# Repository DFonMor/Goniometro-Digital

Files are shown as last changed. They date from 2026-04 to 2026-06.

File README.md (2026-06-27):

# Goniometro-Digital
Repositório para o desenvolvimento de um dispositivo para a disciplina de Projeto Integrador em Engenharia Mecatrônica

# Introdução

O presente projeto tem como objetivo o desenvolvimento de um goniômetro digital, destinado à medição da amplitude de movimento de articulações, com foco em aplicações na área de fisioterapia. Diferentemente dos modelos analógicos tradicionais, que dependem de leitura manual e anotação dos resultados, a solução proposta busca automatizar tanto a aquisição quanto o armazenamento dos dados.

O sistema será composto por um sensor de posição acoplado a um microcontrolador (ESP32), responsável por realizar a leitura e o processamento dos dados, além de comunicar as medições a um aplicativo mobile por meio de conexão sem fio. O aplicativo permitirá a visualização em tempo real, bem como o armazenamento do histórico de medições associadas a cada paciente.

Essa abordagem visa aumentar a precisão das medições, reduzir erros humanos e proporcionar maior praticidade ao profissional durante o acompanhamento da evolução dos pacientes, centralizando todas as informações em uma única plataforma digital.

# Sistema

O sistema proposto é composto por três módulos principais: o dispositivo embarcado, o aplicativo mobile e o mecanismo de armazenamento de dados.

O dispositivo embarcado é baseado no microcontrolador ESP32, responsável pela aquisição dos sinais provenientes do sensor por meio de seu conversor analógico-digital (ADC). A partir dessas leituras, o sistema realiza o processamento necessário para obtenção da medida de ângulo das articulações.

A comunicação entre o dispositivo e o usuário é realizada por meio de Bluetooth Low Energy (BLE), permitindo a transmissão dos dados em tempo real para um dispositivo móvel. A escolha do BLE foi motivada pelo seu baixo consumo energético, simplicidade de conexão com smartphones e adequação a aplicações portáteis, características essenciais para o contexto de uso do goniômetro.

O aplicativo mobile será desenvolvido utilizando o framework React Native, sendo responsável por estabelecer a conexão com o ESP32, receber os dados transmitidos e apresentá-los ao usuário em tempo real. Além disso, o aplicativo permitirá o armazenamento das medições, possibilitando o acompanhamento do histórico de cada paciente, conforme previsto no escopo do projeto.

## Back-End

O back-end do projeto é composto pelo firmware desenvolvido para o microcontrolador ESP32, responsável pela leitura do sensor analógico e transmissão dos dados via Bluetooth Low Energy (BLE). O firmware foi implementado em C++ utilizando o framework Arduino, com as seguintes características:

- **Leitura analógica**: O ESP32 realiza a leitura do sinal proveniente de um potenciômetro linear (ou sensor de ângulo) conectado a um pino ADC, com resolução de 12 bits (0–4095) e atenuação configurada para a faixa de 0 a 3,3 V.

- **Conversão para tensão**: O valor cru do ADC é convertido para tensão (em volts) utilizando a referência de 3,3 V, resultando em valores entre 0 e 3,3 V.

- **Comunicação BLE**: O ESP32 atua como periférico BLE, anunciando o serviço com UUID personalizado e disponibilizando uma característica para leitura/escrita/notificação. O dispositivo aguarda comandos enviados pelo aplicativo mobile e responde com pacotes de dados estruturados.

- **Protocolo de comunicação**: Os dados são transmitidos em pacotes com o formato `[FLAG_1][FLAG_2][LEN][DATA ...][CHECKSUM]`, onde:
  - `FLAG_1` e `FLAG_2` identificam o tipo de mensagem (requisição, resposta ou calibração);
  - `LEN` indica o número de bytes em `DATA` + `CHECKSUM`;
  - `CHECKSUM` é calculado como a soma simples dos bytes anteriores.
  - Os comandos suportados incluem `START` (início da transmissão), `STOP` (interrupção da transmissão) e `CALIBRATE` (solicitação de calibração do zero).

- **Resposta do dispositivo**: O ESP32 envia pacotes de resposta contendo a tensão medida em centésimos de volt (HIGH e LOW), juntamente com o checksum correspondente.

- **Persistência de calibração**: O firmware armazena o offset de calibração (valor do ADC correspondente ao ângulo zero) na memória flash (via `Preferences`), garantindo que a calibração seja mantida mesmo após reinicializações.

O firmware foi projetado para ser estável, com baixo consumo de energia e compatível com as especificações do hardware do goniômetro.

---

## Front-End

O desenvolvimento do front-end é realizado por meio de um aplicativo mobile utilizando o framework React Native com Expo. O aplicativo é responsável por estabelecer a interface entre o usuário e o dispositivo embarcado, permitindo a visualização, interação e armazenamento das medições realizadas.

A arquitetura do aplicativo foi organizada em camadas (serviços, componentes, utilitários e contextos) para facilitar a manutenção e a evolução do código. A comunicação com o ESP32 é feita via Bluetooth Low Energy (BLE) utilizando a biblioteca `react-native-ble-plx`, com suporte a modo de simulação (mock) para testes sem hardware.

### Funcionalidades implementadas

- **Conexão com o dispositivo**  
  Busca e conexão com o ESP32 via BLE, com indicação visual do status (conectado, conectando, desconectado). O aplicativo permite iniciar/parar a transmissão de dados (comandos START/STOP) e desconectar completamente, mantendo a lógica de controle separada para maior flexibilidade.

- **Recepção e processamento de dados em tempo real**  
  Leitura contínua dos pacotes BLE enviados pelo microcontrolador, com validação de integridade (verificação de checksum) e parsing dos campos. Os dados de tensão são convertidos em ângulo utilizando uma função de mapeamento linear calibrada. Um filtro de mediana com janela de 12 amostras é aplicado para suavizar as leituras e reduzir ruídos.

- **Exibição das medições**  
  Apresentação clara e direta dos valores de tensão (V) e ângulo (°) na tela principal, com atualização dinâmica a cada novo pacote recebido. O ângulo é exibido em destaque, facilitando a leitura durante o uso clínico.

- **Perfil do Paciente Expandido**  
  Gerenciamento completo de pacientes, com criação, edição e exclusão de perfis. Cada perfil armazena:
  - Nome (obrigatório)
  - Data de nascimento
  - Sexo (Masculino, Feminino, Outro)
  - Lado afetado (Direito, Esquerdo, Ambos)
  - Diagnóstico / condição clínica
  - Número de prontuário
  - Telefone para contato
  A edição é feita por meio de um modal com formulário organizado, incluindo campos com máscara (data) e seletores (sexo, lado afetado).

- **Seleção de Movimento**  
  Antes de salvar uma medição, o usuário pode selecionar o tipo de movimento realizado (Punho, Cotovelo, Joelho, Tornozelo, Outro). O movimento é registrado junto com a medição e exibido no histórico, permitindo filtrar ou categorizar os dados futuramente.

- **Registro de medições**  
  Funcionalidade para salvar a medição atual no perfil do paciente ativo, associando-a a um timestamp e ao movimento selecionado. Os dados são armazenados localmente no dispositivo utilizando AsyncStorage, com estrutura organizada por paciente.

- **Histórico completo com anotações e exclusão**  
  Tela dedicada (modal) que exibe todas as medições de um paciente, com as seguintes ações por item:
  - **Visualização de anotação**: cada medição pode ter uma anotação de texto livre, exibida na lista com suporte a expansão/colapso (ver mais/ver menos).
  - **Edição de anotação**: ao tocar no ícone ⋮, o usuário pode adicionar ou editar a anotação através de um modal com campo de texto.
  - **Exclusão de medição**: opção para deletar uma medição com confirmação, removendo-a do armazenamento e da lista.

- **Calibração do zero**  
  O aplicativo permite calibrar o ponto de zero (0°) do sensor, armazenando a tensão correspondente a essa posição no perfil do paciente. A calibração é aplicada em todas as medições subsequentes daquele paciente, ajustando a conversão tensão→ângulo de forma personalizada.

- **Modo de simulação (Mock)**  
  Para facilitar o desenvolvimento e testes sem o hardware físico, o aplicativo possui um modo de simulação que gera dados sintéticos (variação senoidal do ângulo entre 0° e 180°) e os envia com a mesma estrutura de pacotes do ESP32 real. Esse modo é ativado por uma flag (`USE_MOCK`) no código.

### Armazenamento

Atualmente, o aplicativo utiliza o **AsyncStorage** para persistência local dos dados, com as seguintes chaves principais:

- `pacientes`: lista de todos os pacientes cadastrados.
- `medicoes_{id}`: array de medições de cada paciente, contendo ângulo, tensão, movimento, timestamp e anotação.
- `calibracao_{id}`: dados de calibração (tensão de zero) para cada paciente.

A estrutura de dados foi projetada para ser extensível, e o aplicativo já realiza migração automática de versões antigas, garantindo compatibilidade com registros existentes.

### Estratégia de desenvolvimento

O desenvolvimento seguiu uma abordagem incremental, com as seguintes etapas concluídas:

1. ✅ Implementação da interface básica e simulação de dados (mock);
2. ✅ Integração com o módulo de comunicação BLE (real e mock);
3. ✅ Implementação das funcionalidades de armazenamento local (AsyncStorage);
4. ✅ Desenvolvimento da visualização de histórico com anotações e exclusão;
5. ⏳ Integração futura com serviços em nuvem (planejada para versões posteriores).

### Próximos passos (futuro)

- Exportação de dados em formato CSV/PDF para relatórios;
- Sincronização com nuvem (Firebase ou outro backend) para compartilhamento entre dispositivos;
- Gráficos de evolução do paciente ao longo do tempo;
- Suporte a múltiplos idiomas;
- Melhorias na interface para tablets e telas maiores.

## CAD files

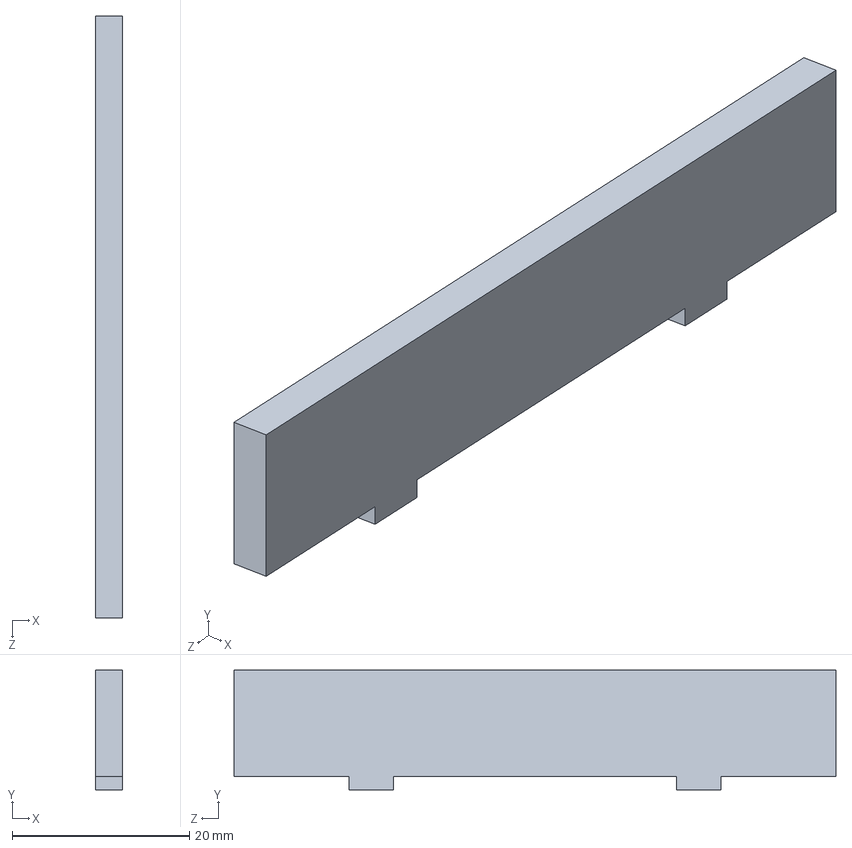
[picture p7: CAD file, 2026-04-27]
Modelos 3D/parede_bateria_esp32.SLDPRT
3.00 x 13.5 x 68.0 mm

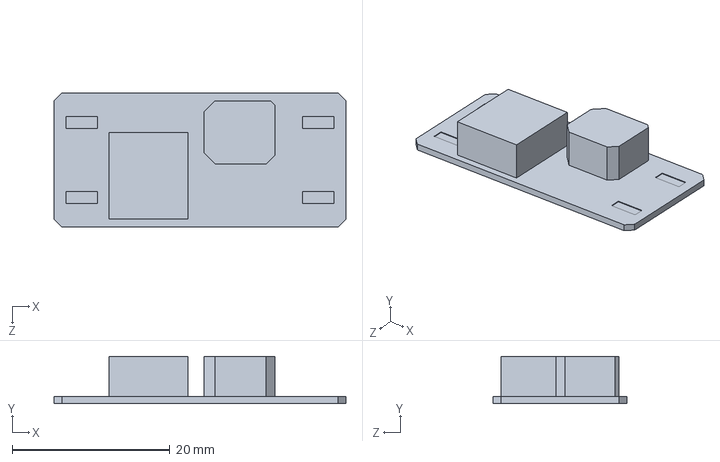
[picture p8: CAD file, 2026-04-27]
Modelos 3D/modulo_step_up.SLDPRT
37.0 x 6.00 x 17.0 mm

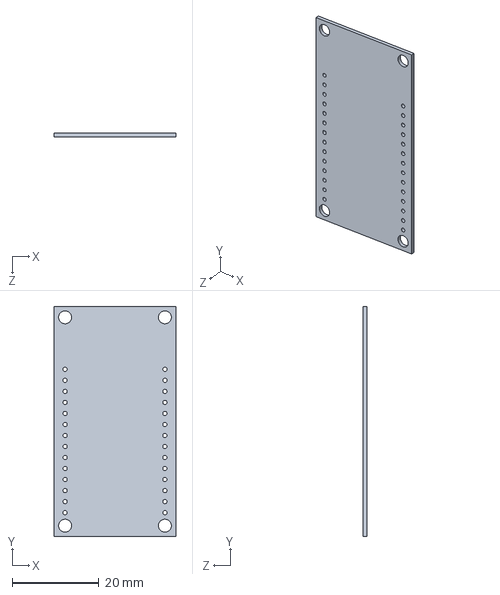
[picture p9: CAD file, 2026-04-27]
Modelos 3D/ESP32_30pins.SLDPRT
28.0 x 53.0 x 0.9 mm

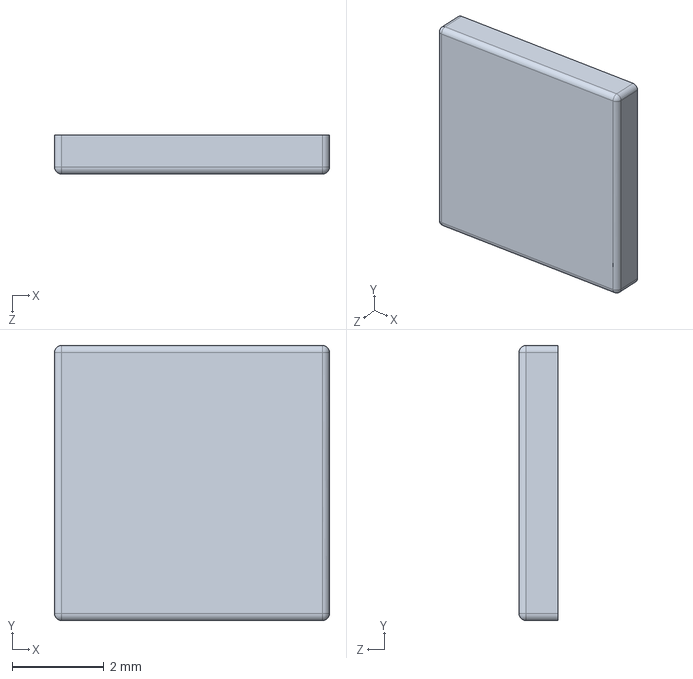
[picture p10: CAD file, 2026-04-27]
Modelos 3D/ESP32_processor.SLDPRT
6.00 x 6.00 x 0.85 mm

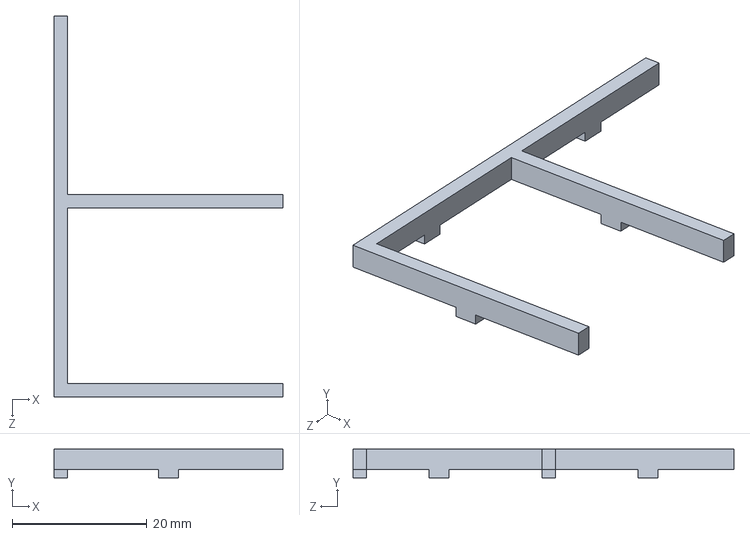
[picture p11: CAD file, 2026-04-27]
Modelos 3D/sup_latearal_pcb_sensor.SLDPRT
34.0 x 4.25 x 56.5 mm

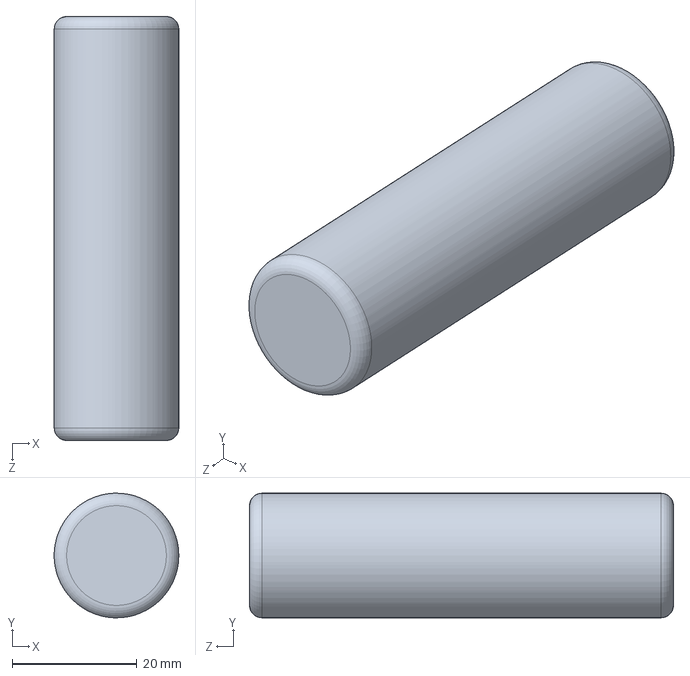
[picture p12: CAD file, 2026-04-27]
Modelos 3D/bateria.SLDPRT
20.0 x 20.0 x 68.0 mm

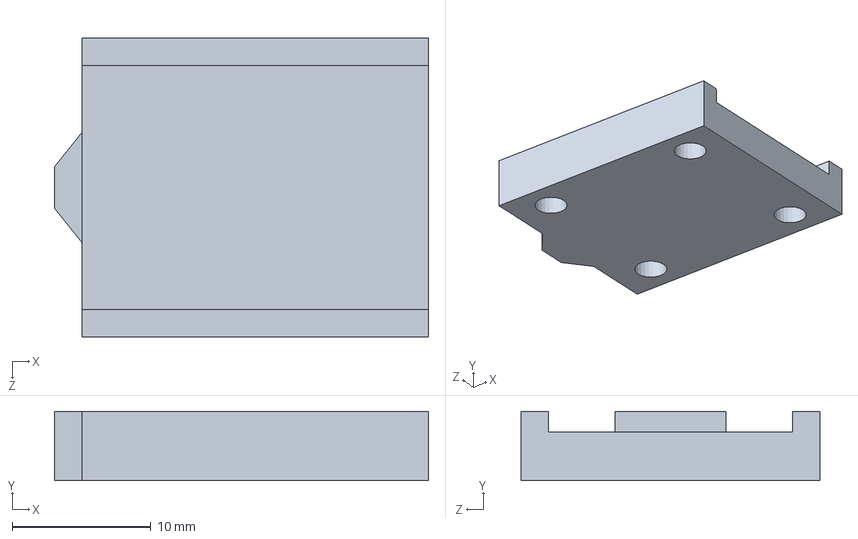
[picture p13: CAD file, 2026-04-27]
Modelos 3D/sup_mod_carregamento.SLDPRT
27.0 x 5.00 x 21.6 mm

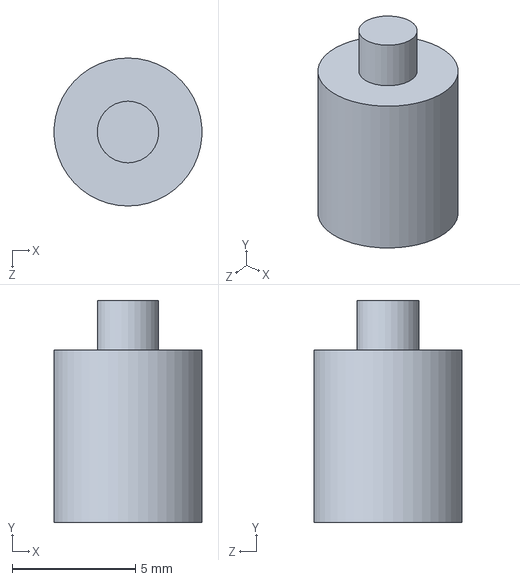
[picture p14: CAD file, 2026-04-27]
Modelos 3D/pino_suporte.SLDPRT
5.99 x 9.00 x 6.00 mm

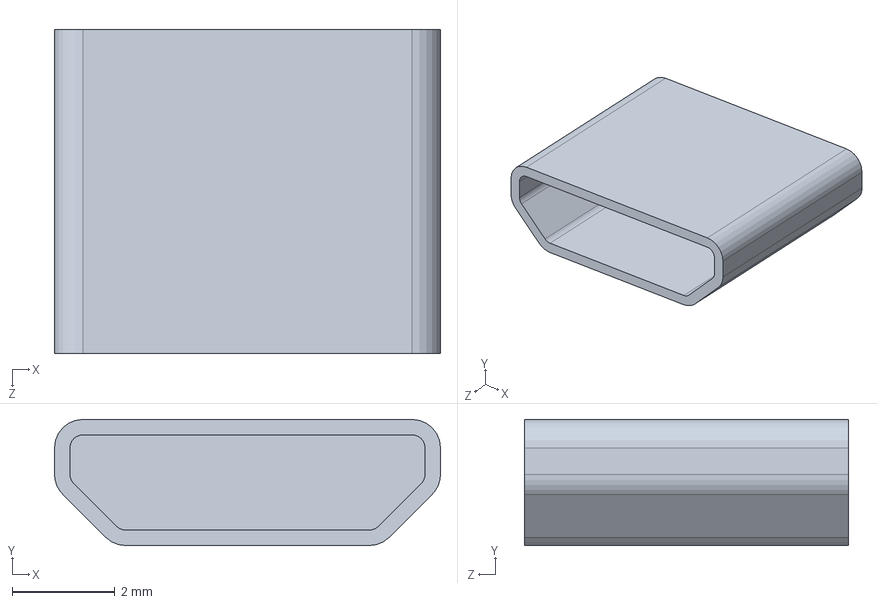
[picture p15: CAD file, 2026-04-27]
Modelos 3D/esp32_connector.SLDPRT
7.50 x 2.45 x 6.30 mm

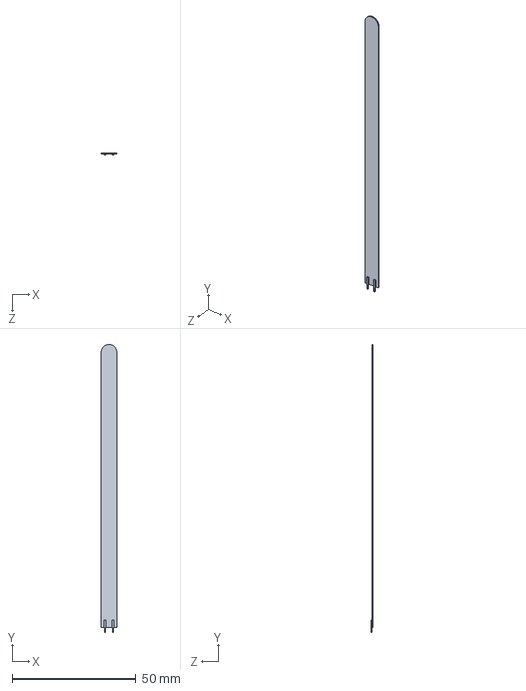
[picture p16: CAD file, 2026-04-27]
Modelos 3D/sensor_res_variavel.SLDPRT
6.35 x 116.3 x 1.00 mm

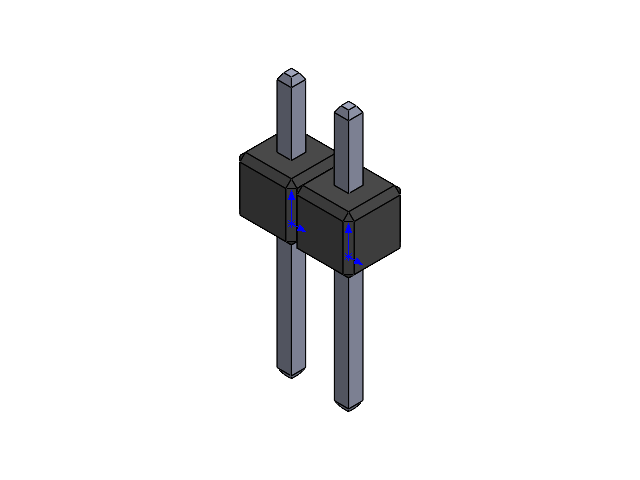
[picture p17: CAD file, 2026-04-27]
Modelos 3D/conj_pinos_2.SLDASM
pino x 2

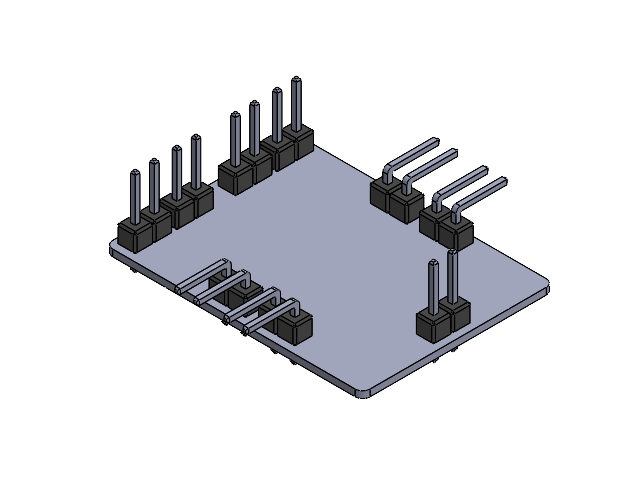
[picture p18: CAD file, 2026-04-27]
Modelos 3D/pcb_sensor_montagem.SLDASM
pcb_sensor
pino x 10
pino_90 x 8

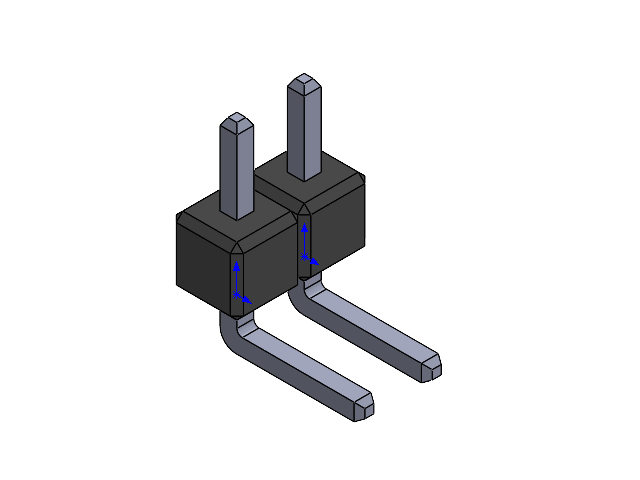
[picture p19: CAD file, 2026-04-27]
Modelos 3D/conj_pinos_90_2.SLDASM
pino_90 x 2

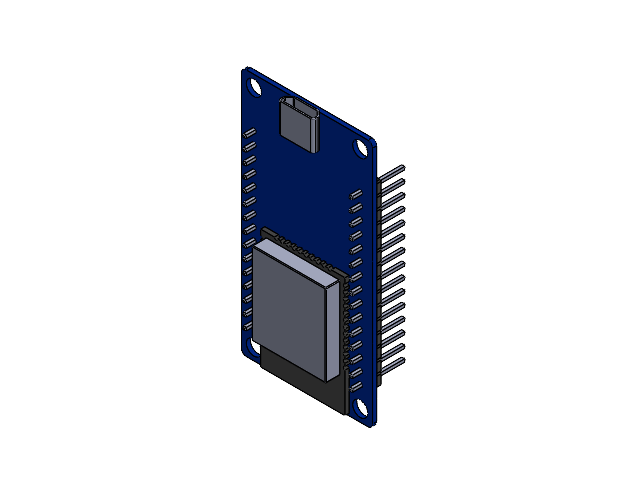
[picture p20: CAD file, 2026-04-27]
Modelos 3D/ESP32.SLDASM
ESP32_board
esp32_connector
ESP32_processor_base
ESP32_processor
pino x 30

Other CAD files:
Modelos 3D/goniometro.SLDASM
Modelos 3D/conj_pinos.SLDASM
Modelos 3D/case.SLDASM
Modelos 3D/modulo_carregamento.SLDASM
Modelos 3D/ESP32_board.SLDPRT
Modelos 3D/ESP32_processor_base.SLDPRT
Modelos 3D/case_inferior.SLDPRT
Modelos 3D/case_superior.SLDPRT
Modelos 3D/pcb_modulo_carregamento.SLDPRT
Modelos 3D/pcb_sensor.SLDPRT
Modelos 3D/pino.SLDPRT
Modelos 3D/pino_90.SLDPRT
Modelos 3D/sup_diant_esp32.SLDPRT
Modelos 3D/suporte_esp.SLDPRT

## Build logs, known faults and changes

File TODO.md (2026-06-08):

# TODO 
---

## Front-End (Responsável: Front-End)

- [x] Criar estrutura inicial do app (React Native)
- [x] Implementar interface básica com dados simulados
- [x] Preparar tela para exibição em tempo real
- [x] Estruturar fluxo de salvamento de medições
- [x] Implementar persistência local
- [x] Desenvolver visualização de histórico
- [x] Integrar comunicação BLE (dependente do firmware)
- [x] Build inicial para teste com ESP
- [x] Implementar calibração de referência (definição de 0°)
- [x] Adicionar função STOP
- [ ] Estrutura de pacientes

---

## Firmware / ESP32 (Dependências críticas)

- [x] Testar velocidade da comunicação bluetooth
- [x] Padronizar o envio de dados como dois bytes
- [x] Realizar leitura da entrada para selecionar entre início da coleta e final da coleta
- [x] Mudar de Bluetooth SPP para Bluetooth BLE (veja sobre: BLEDevice.h, BLEServer.h, BLEUtils.h e BLE2902.h.)
- [x] Verificar a conversão (é 5V mesmo ou 3.3V?)
- [x] Adicionar byte de sincronização (seria adicionar um header tipo SerialBT.write(0xAA), pois o app não sabe se perdeu o byte)
- [x] Testar comunicação com App:
- [x] Encontrou o ESP?
- [x] Conectou?
- [x] Recebeu o notify?
- [x] O checksum passou?
- [x] A tensão apareceu?

---

## Eletrônica

- [x] Alterar comprimento dos cabos
- [x] Revisar as ligações
- [x] Fazer testes

---

## Mecânica

- [x]  Inserir abertura para carregamento
- [x]  Inserir chave On/Off
- [x]  Impressão teste
- [x]  Verificar folgas
- [x]  Terminar modelagem da fixação do sensor ao manguito
- [x]  Terminar desenvolvimento da alça de fixação

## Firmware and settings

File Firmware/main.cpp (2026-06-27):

/*
====================================================
Formato das mensagens BLE
====================================================

Estrutura geral:

[FLAG_1][FLAG_2][LEN][DATA ...][CHECKSUM]

Onde:
- FLAG_1 e FLAG_2 identificam o tipo da mensagem
- LEN indica quantidade de bytes em DATA + CHECKSUM
- CHECKSUM = soma simples dos bytes anteriores

----------------------------------------------------
Comandos recebidos pelo ESP32
----------------------------------------------------

START:
B1 0E 02 00 C1

STOP:
B1 0E 02 01 C2

----------------------------------------------------
Resposta enviada pelo ESP32
----------------------------------------------------

B1 0A 03 HIGH LOW CHECKSUM

HIGH + LOW:
valor da tensão em centésimos de volt

Exemplo:
01 2C = 300 -> 3.00V

====================================================
*/

#include <Arduino.h>
#include <BLEDevice.h>
#include <BLEServer.h>
#include <BLEUtils.h>
#include <BLE2902.h>



#define ADC_PIN 34

#define FLAG_REQUEST 0xB10E
#define FLAG_ANSWER  0xB10A

#define START 0x00
#define STOP  0x01

typedef struct {
  uint8_t flag_1 = 0xB1;
  uint8_t flag_2 = 0x0A;
  uint8_t len = 3;
  uint8_t high;
  uint8_t low;
  uint8_t sum = 0;
} Packet;

const char *BT_NAME = "ESP32_ADC";

#define SERVICE_UUID        "12345678-1234-1234-1234-1234567890ab"
#define CHARACTERISTIC_UUID "abcd1234-5678-90ab-cdef-1234567890ab"

float volts = 3.3;
int resolution = 1 << 12;

bool coletando = false;
bool deviceConnected = false;

BLECharacteristic *pCharacteristic;

void enviarLeituraADC();
void verificarComandoBluetooth(uint8_t *data, size_t size);

class ServerCallbacks : public BLEServerCallbacks {
  void onConnect(BLEServer *pServer) {
    deviceConnected = true;
    Serial.println("BLE conectado");
  }

  void onDisconnect(BLEServer *pServer) {
    deviceConnected = false;
    coletando = false;
    Serial.println("BLE desconectado");

    pServer->startAdvertising();
  }
};

class CharacteristicCallbacks : public BLECharacteristicCallbacks {
  void onWrite(BLECharacteristic *characteristic) {
    std::string value = characteristic->getValue();

    if (value.length() > 0) {
      verificarComandoBluetooth((uint8_t *)value.data(), value.length());
    }
  }
};

void setup() {
  Serial.begin(115200);

  pinMode(ADC_PIN, INPUT);

  analogReadResolution(12);
  analogSetPinAttenuation(ADC_PIN, ADC_11db);

  BLEDevice::init(BT_NAME);

  BLEServer *pServer = BLEDevice::createServer();
  pServer->setCallbacks(new ServerCallbacks());

  BLEService *pService = pServer->createService(SERVICE_UUID);

  pCharacteristic = pService->createCharacteristic(
    CHARACTERISTIC_UUID,
    BLECharacteristic::PROPERTY_READ   |
    BLECharacteristic::PROPERTY_WRITE  |
    BLECharacteristic::PROPERTY_NOTIFY
  );

  pCharacteristic->addDescriptor(new BLE2902());
  pCharacteristic->setCallbacks(new CharacteristicCallbacks());

  pService->start();

  BLEAdvertising *pAdvertising = BLEDevice::getAdvertising();
  pAdvertising->addServiceUUID(SERVICE_UUID);
  pAdvertising->setScanResponse(true);
  pAdvertising->setMinPreferred(0x06);
  pAdvertising->setMinPreferred(0x12);

  BLEDevice::startAdvertising();

  Serial.println("BLE iniciado");
}

void loop() {
  if (coletando) {
    enviarLeituraADC();
  }
  delay(100);
}

void verificarComandoBluetooth(uint8_t *data, size_t size) {
  if (size < 3) return;

  Serial.println("recebeu mensagem");

  uint8_t b1 = data[0];
  uint8_t b2 = data[1];
  uint8_t len = data[2];

  if (size < 3 + len) return;

  uint8_t *cmd = (uint8_t *)malloc(len);
  if (cmd == NULL) return;

  memcpy(cmd, &data[3], len);

  uint16_t flag = ((uint16_t)b1 << 8) | b2;

  if (flag != FLAG_REQUEST) {
    Serial.println("Flag errada");
    free(cmd);
    return;
  }

  uint8_t sum = b1 + b2 + len;

  for (int i = 0; i < (len - 1); ++i) {
    sum += cmd[i];
  }

  if (sum != cmd[len - 1]) {
    Serial.println("sum errado");
    free(cmd);
    return;
  }

  Serial.println("verificando comando");

  switch (cmd[0]) {
    case START:
      coletando = true;
      Serial.println("START");
      break;

    case STOP:
      coletando = false;
      Serial.println("STOP");
      break;
  }

  free(cmd);
}

void enviarLeituraADC() {
  if (!deviceConnected) return;

  Packet pacote;

  int adcRaw = analogRead(ADC_PIN);

  float tensao = adcRaw * (volts / resolution);

  uint16_t valor = (uint16_t)(tensao * 100.0);

  pacote.high = (valor >> 8) & 0xFF;
  pacote.low = valor & 0xFF;

  pacote.sum += pacote.flag_1 + pacote.flag_2 + pacote.len + pacote.high + pacote.low;

  pCharacteristic->setValue((uint8_t *)&pacote, sizeof(Packet));
  pCharacteristic->notify();
}

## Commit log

2026-04-27 Modelos 3D
    [ESP32.SLDASM, ESP32_30pins.SLDPRT, ESP32_board.SLDPRT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]
2026-04-27 Create TODO
    Lista de o que precisamos fazer
2026-05-02 codigo do esp32
2026-06-08 correções de BLE + criação do APK
2026-06-10 fix: adc resolution
2026-06-12 Atualiza conversao de tensao para graus
2026-06-24 filtro de mediana
2026-06-27 Sistema novo de perfil de pacientes
2026-06-27 Nova maneira de exibir o histórico
2026-06-27 Versão 1.0.1
    Adicionadas as funções de anotações no histórico, de exclusão de medições erradas e perfil de paciente com mais informações.
2026-06-28 Correção de crash
2026-06-28 fix: valor mudado para 164
2026-06-29 feat: ajusta filtro de mediana para 15 amostras
